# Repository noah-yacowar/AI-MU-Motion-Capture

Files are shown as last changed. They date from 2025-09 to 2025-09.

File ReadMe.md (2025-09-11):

# The "AI-MU" Motion-Capture Project

ESP8266 + BNO08x (080/085) based motion capture system that streams IMU data over Wi-Fi into Unity.  
The ecosystem includes a **mobile app** for QR code–based pairing of IMU suits and servers, making setup fast and reliable. This was chosen especially for commercial use cases where multiple users will be using the system daily. Here, a simple fixed connection from the sensor directly to the server is not flexible enough for all workflows.
The Unity application performs real-time skeleton reconstruction, visualization, and recording, with the ability to export captured motion to **BVH** for animation workflows.

---

## 📸 Overview

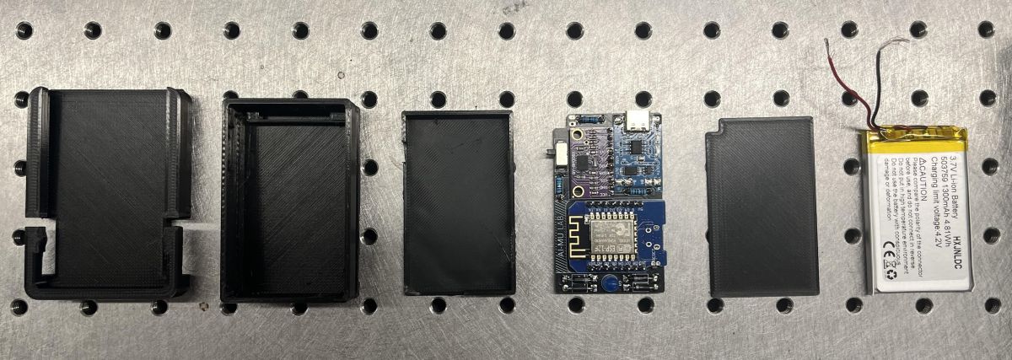
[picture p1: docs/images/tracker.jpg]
Tracker Hardware
  
*Custom ESP8266 D1 Mini + BNO08x tracker module*

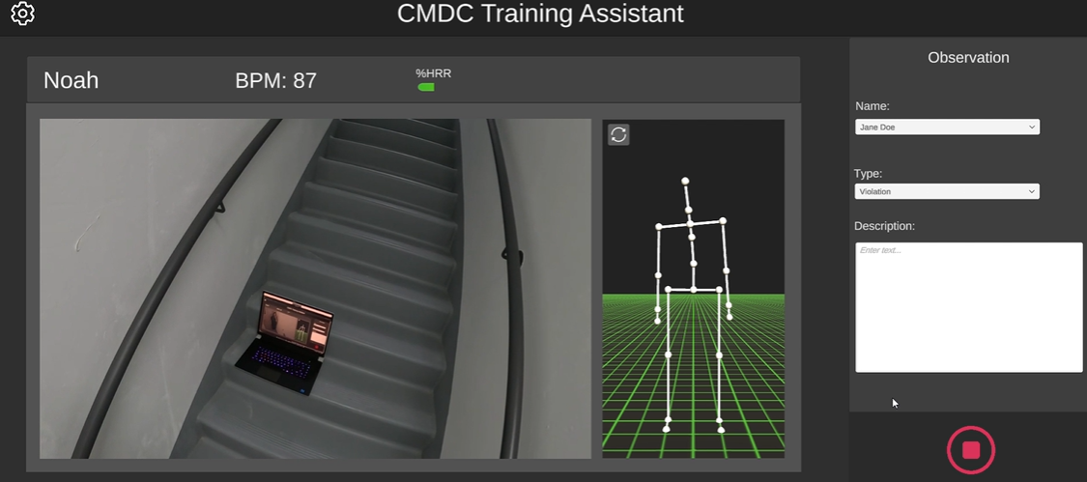
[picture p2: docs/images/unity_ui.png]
Unity UI
  
*Unity interface showing live skeleton and recording controls*

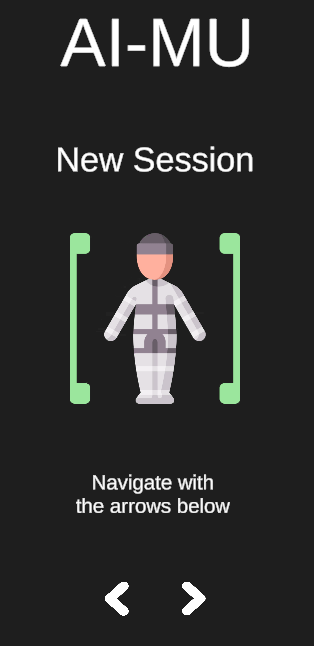
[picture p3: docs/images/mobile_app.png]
Mobile App
  
*Mobile app used to scan QR code of IMU suit and connect to server*

---

## ✨ Features

- **Low-cost IMU Trackers**: ESP8266 D1 Mini boards with BNO080/BNO085 IMUs.
- **Mobile App Integration**: Scan a QR code on the IMU suit to automatically configure and connect to the server.  
- **Wi-Fi Data Streaming**: Fast UDP packets (~100 Hz) from multiple trackers.
- **Real-time Visualization**: Unity app reconstructs skeletons live.
- **Calibration Tools**: Mounting error correction + baseline yaw alignment.
- **Multi-Participant Support**: Capture multiple people simultaneously.
- **Recording & Export**: Save sessions and export to **BVH** (for Blender, Unity, Maya, etc.).

---

## 🖥️ Software

- **Firmware**: C++/Arduino code running on each D1 Mini, sending IMU quaternions via UDP.  
- **Mobile App**:  
  - Scans QR code on the IMU suit to register tracker IDs.  
  - Connects suit to the Unity server automatically.  
- **Unity App**:  
  - Receives tracker data  
  - Maps IMUs to skeleton joints  
  - Provides calibration tools  
  - Records sessions and exports animations  

---

## 📦 Hardware

Each tracker is built from:

- **ESP8266 D1 Mini (Wemos)**  
- **BNO080 / BNO085 IMU sensor** (I²C connection)  
- **Battery + charging module**  
- 3D printed case (friction-fit lid for quick access)  

📷 Images:  

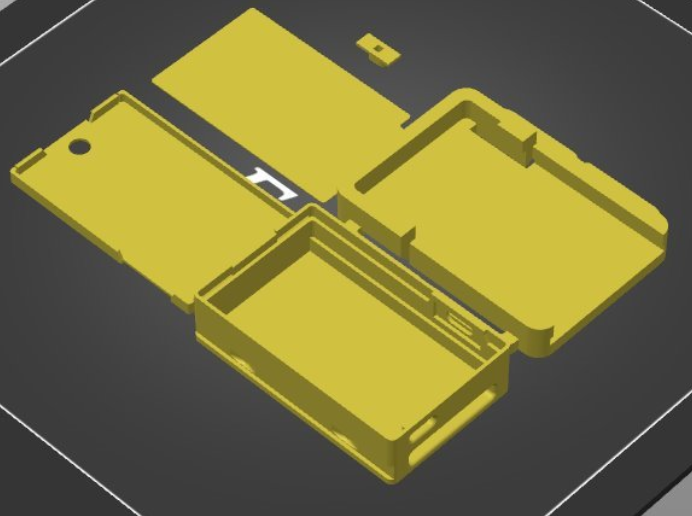
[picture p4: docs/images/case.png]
3D Printed Case
  
*Friction-fit printed case for tracker module*

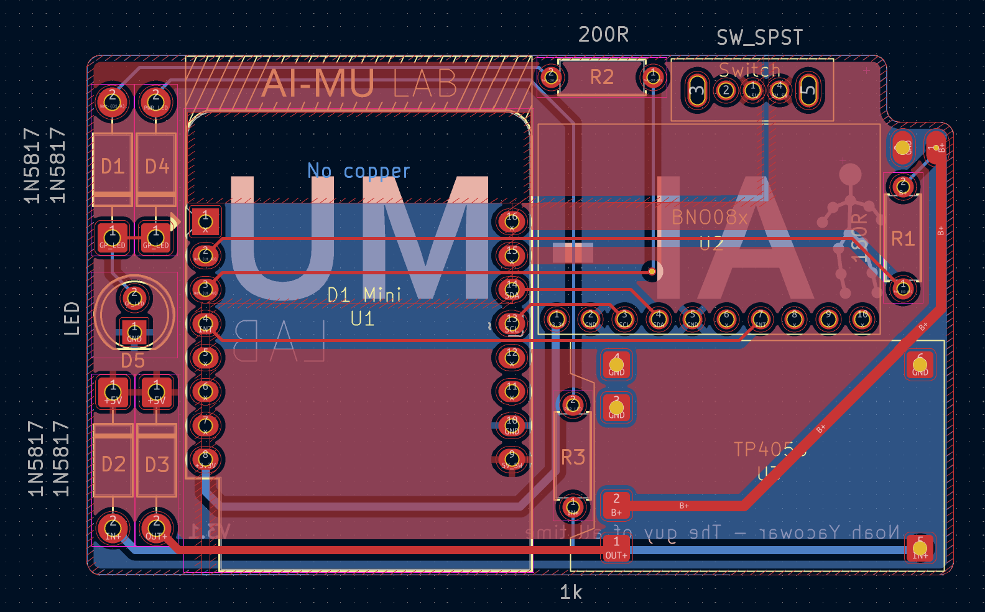
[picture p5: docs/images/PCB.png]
PCB Layout
  
*PCB layout in Kicad*

---

## 🚀 Getting Started

### 1. Clone the Repository
```bash
git clone https://github.com/noah-yacowar/AI-MU-Motion-Capture.git
cd AI-MU-Motion-Capture

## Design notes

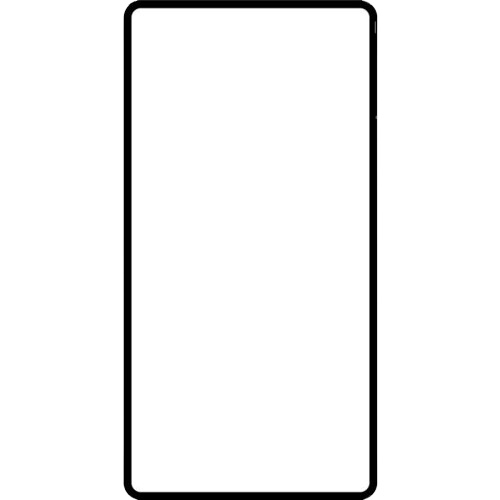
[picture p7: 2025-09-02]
Software/Mobile_App/Assets/MaskShapes/plsss-removebg-preview (2).png

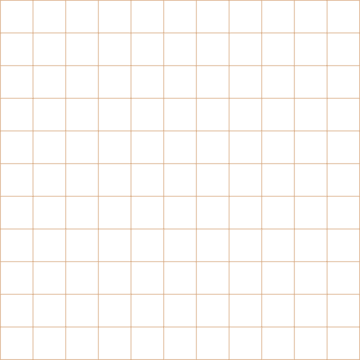
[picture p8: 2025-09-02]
Software/Server_App/Assets/Prefabs/Models/General/Skeleton/GridTexture.png

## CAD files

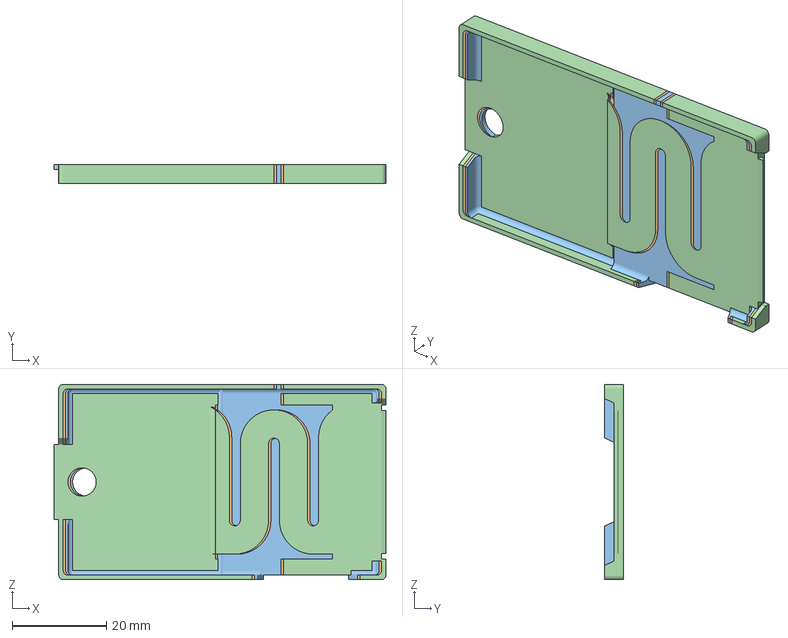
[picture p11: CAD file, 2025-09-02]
Hardware/Case/V2/Slicer/slicer_full_tracker.3mf
70.4 x 4.00 x 41.4 mm
Top_1.5mm.STL
Top_1mm.STL
Top_Friction.STL
Top_V2.4.STL

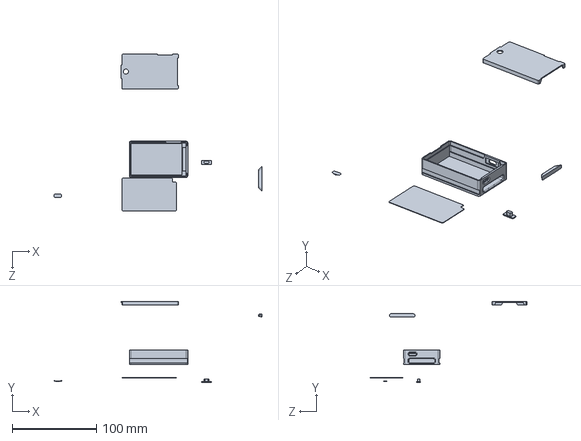
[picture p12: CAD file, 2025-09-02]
Hardware/Case/V2/RoughArea/Tracker_Main_Base.SLDPRT
247.4 x 96.4 x 186.3 mm

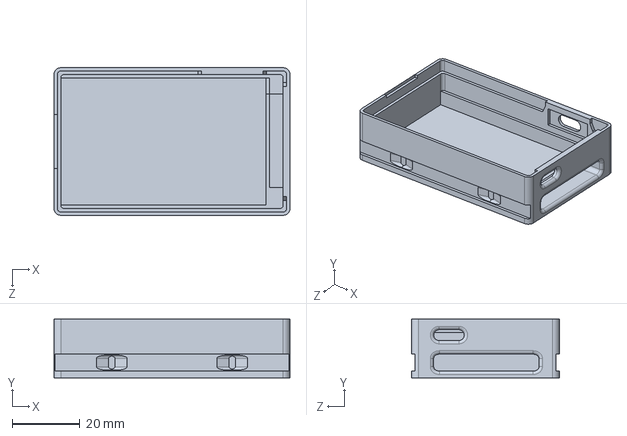
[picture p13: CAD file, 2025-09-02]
Hardware/Case/V2/Main_Body_V2.2.SLDPRT
69.5 x 17.3 x 43.5 mm

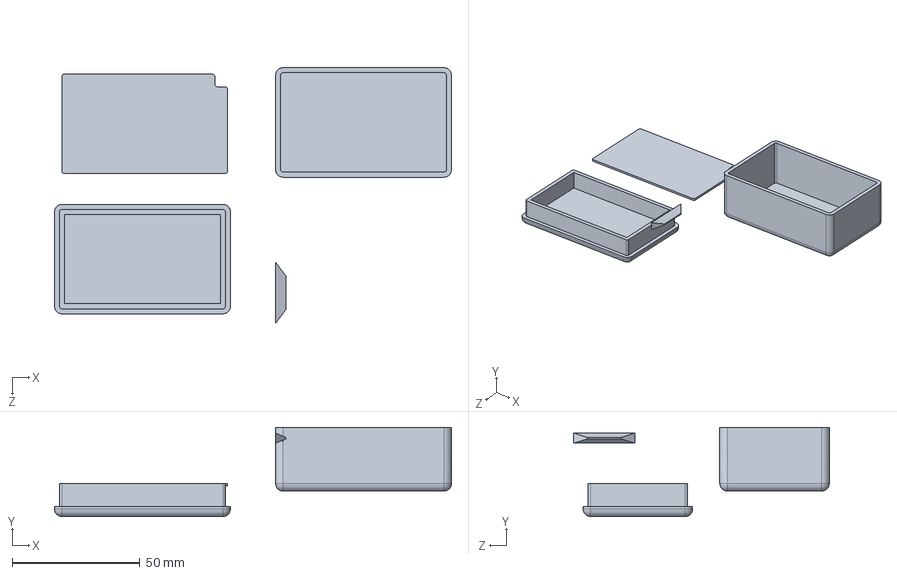
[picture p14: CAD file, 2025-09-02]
Hardware/Case/V2/RoughArea/MoreRough/Tracker_Housing_Top.SLDPRT
155.7 x 35.0 x 100.3 mm

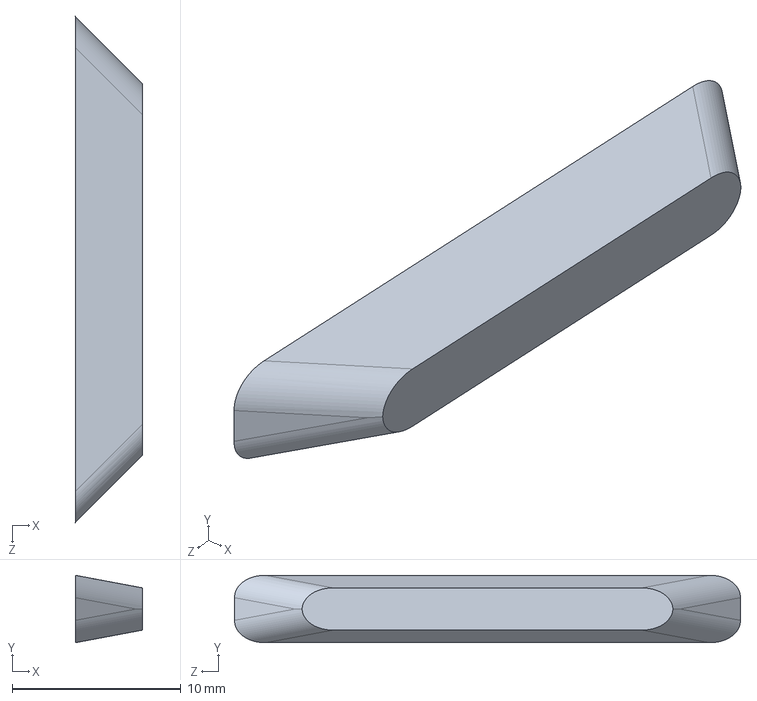
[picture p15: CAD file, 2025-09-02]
Hardware/Case/V2/RoughArea/Tracker_Housing_Connector_Insert.SLDPRT
4.00 x 4.00 x 30.0 mm

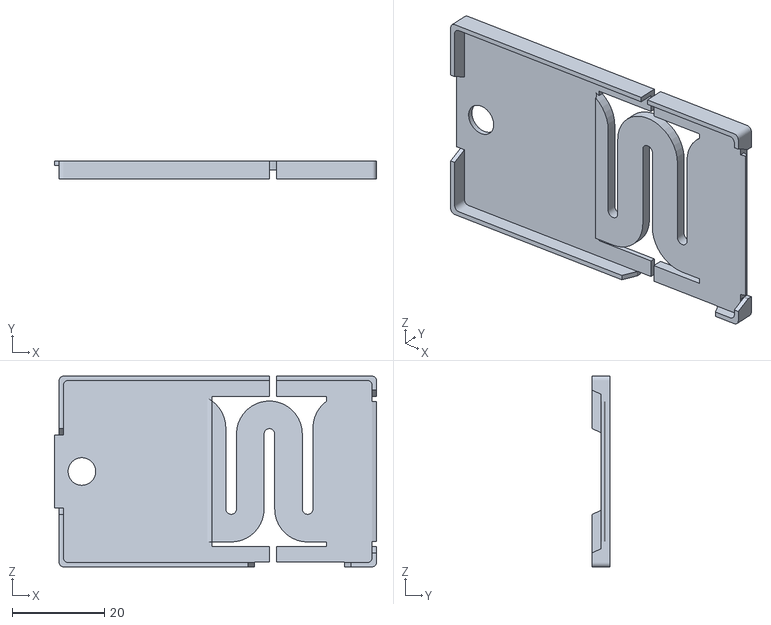
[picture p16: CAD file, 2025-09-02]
Hardware/Case/V2/STL/Top_1.5mm.STL
69.9 x 4.00 x 41.4

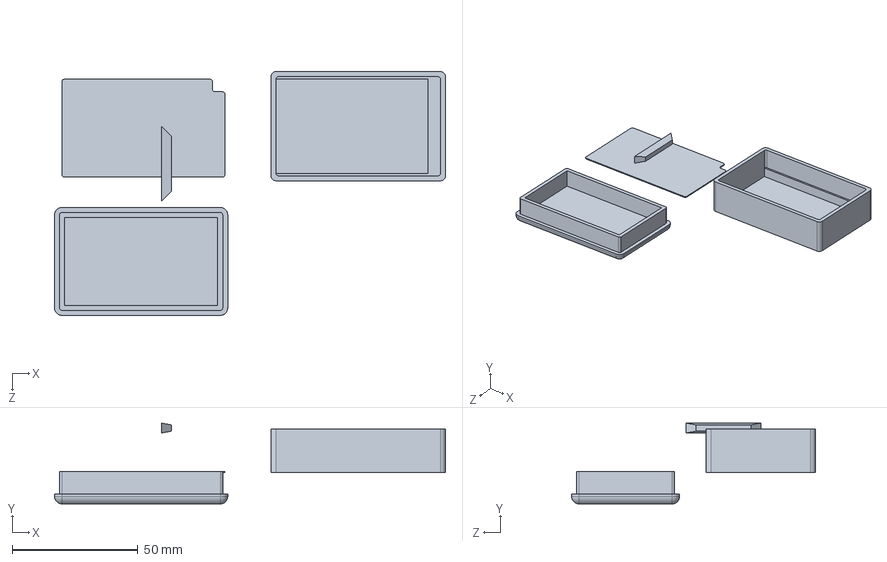
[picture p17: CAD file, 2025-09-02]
Hardware/Case/V2/RoughArea/MoreRough/Tracker_Housing.SLDPRT
155.7 x 32.2 x 97.1 mm

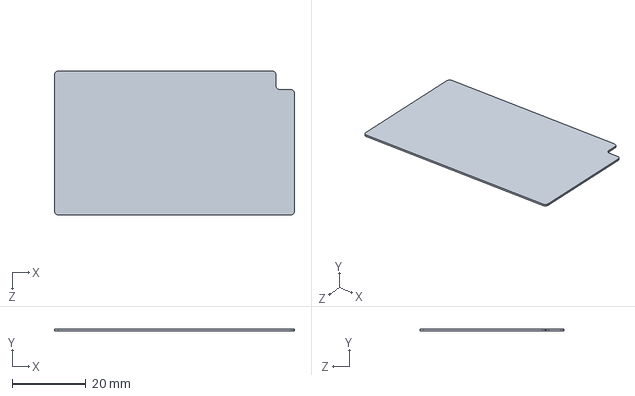
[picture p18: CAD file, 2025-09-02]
Hardware/Case/V2/Seperator_V2.2.SLDPRT
65.0 x 0.5 x 39.0 mm

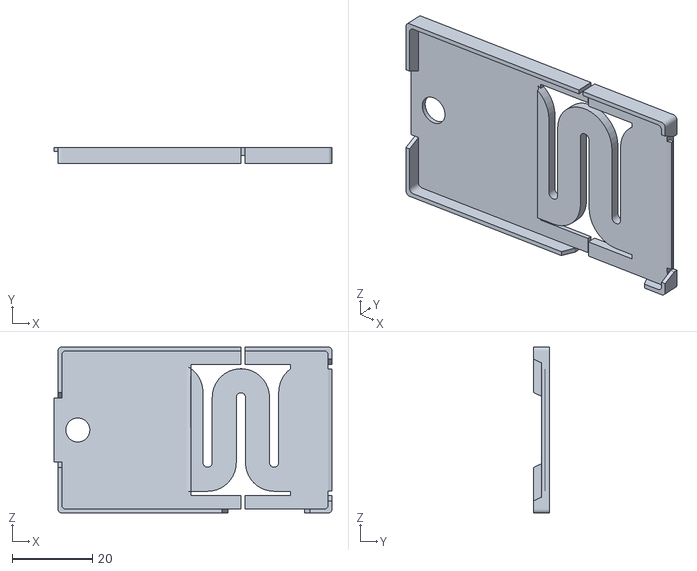
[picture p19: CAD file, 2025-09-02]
Hardware/Case/V2/STL/Top_1mm.STL
69.4 x 4.00 x 41.4

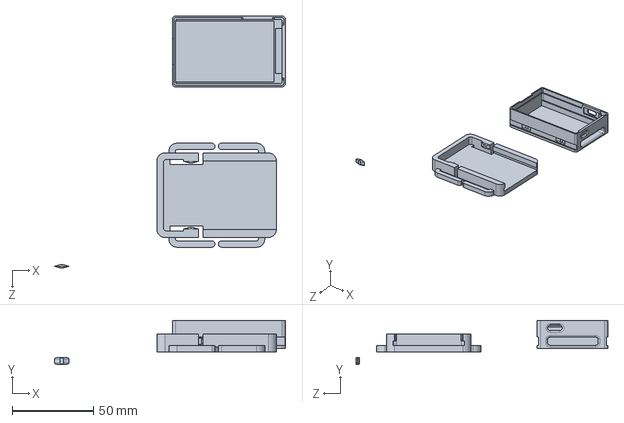
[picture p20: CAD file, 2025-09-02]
Hardware/Case/V2/RoughArea/Tracker_Housing_With_Cutouts.SLDPRT
141.9 x 27.2 x 154.7 mm

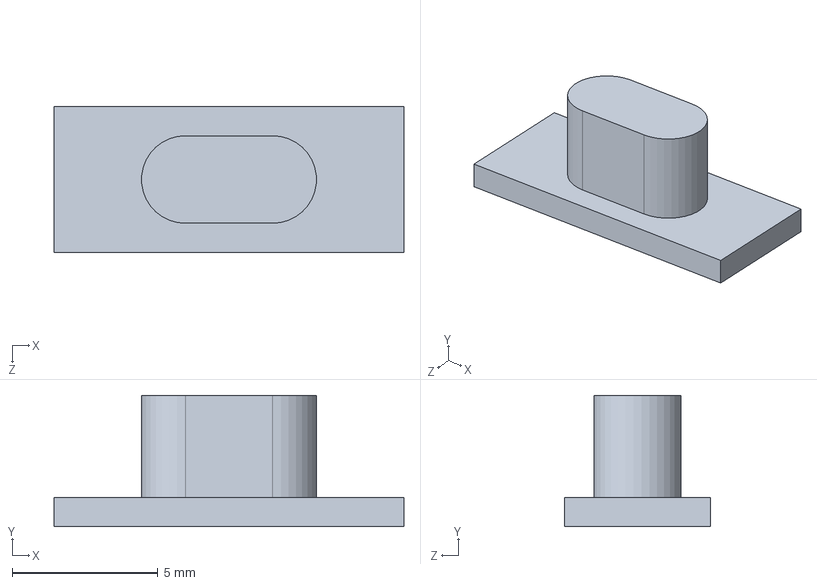
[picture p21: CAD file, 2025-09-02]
Hardware/Case/V2/Switch_V2.2.SLDPRT
12.0 x 4.50 x 5.00 mm

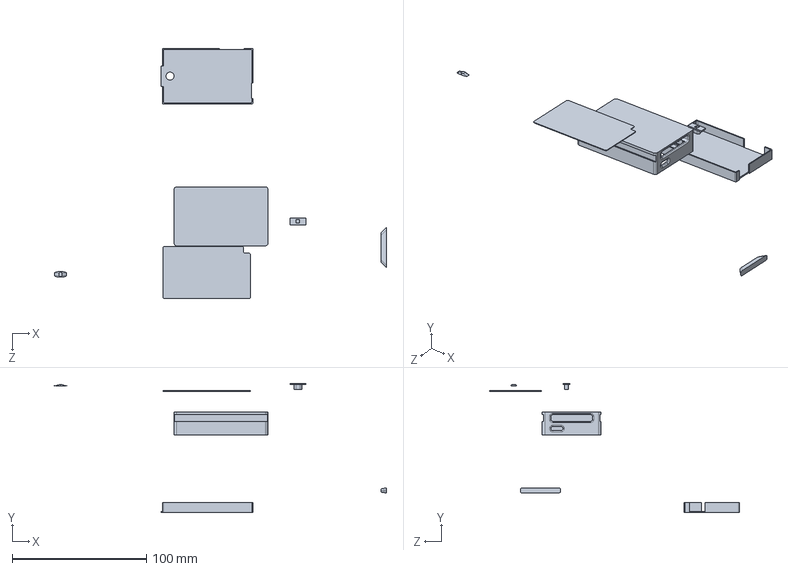
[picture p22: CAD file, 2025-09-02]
Hardware/Case/V2/RoughArea/Top_Housing_V2.1.SLDPRT
247.4 x 96.4 x 186.6 mm

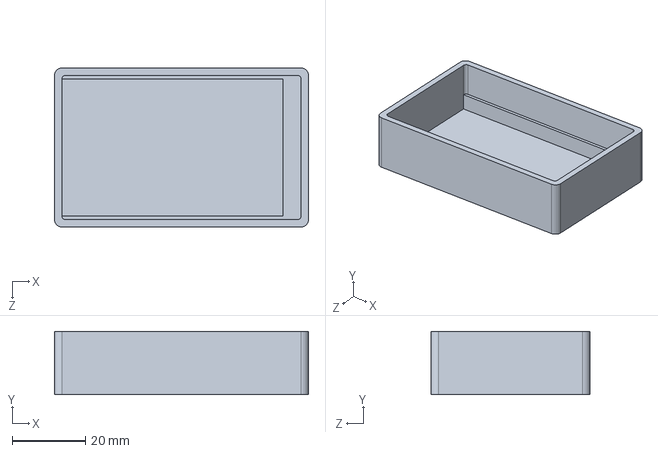
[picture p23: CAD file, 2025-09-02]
Hardware/Case/V2/RoughArea/Tracker_Housing_Body.SLDPRT
69.5 x 17.3 x 43.5 mm

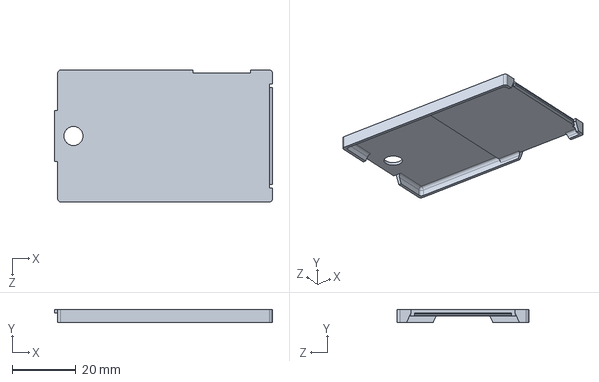
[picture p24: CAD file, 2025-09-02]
Hardware/Case/V2/Top_Friction.SLDPRT
68.4 x 4.00 x 41.4 mm

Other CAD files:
Hardware/Case/V2/RoughArea/Tracker_Housing_Connecting_Piece.SLDPRT
Hardware/Case/V2/Holder_V2.2.SLDPRT
Hardware/Case/V2/RoughArea/Tracker_Housing_Seperator.SLDPRT
Hardware/Case/V2/Top_Unstretched.SLDPRT
Hardware/Case/V1/Body.SLDPRT
Hardware/Case/V1/Divider.SLDPRT
Hardware/Case/V1/Lid.SLDPRT
Hardware/Case/V1/Mount.SLDPRT
Hardware/Case/V1/Print_Files/Body.3mf
Hardware/Case/V1/STL/Body.STL
Hardware/Case/V1/STL/Divider.STL
Hardware/Case/V1/STL/Lid.STL
Hardware/Case/V1/STL/Mount.STL
Hardware/Case/V2/STL/Holder_V2.2.STL
Hardware/Case/V2/STL/Seperator_V2.2.STL
Hardware/Case/V2/STL/Switch_V2.2.STL
Hardware/Case/V2/STL/Top_Friction.STL
Hardware/Case/V2/STL/Top_V2.3.STL
Hardware/Case/V2/STL/Top_V2.4.STL
Hardware/Case/V2/Top_V2.2.SLDPRT
Hardware/Case/V2/Top_V2.3.SLDPRT
Hardware/Case/V2/Top_V2.4.SLDPRT

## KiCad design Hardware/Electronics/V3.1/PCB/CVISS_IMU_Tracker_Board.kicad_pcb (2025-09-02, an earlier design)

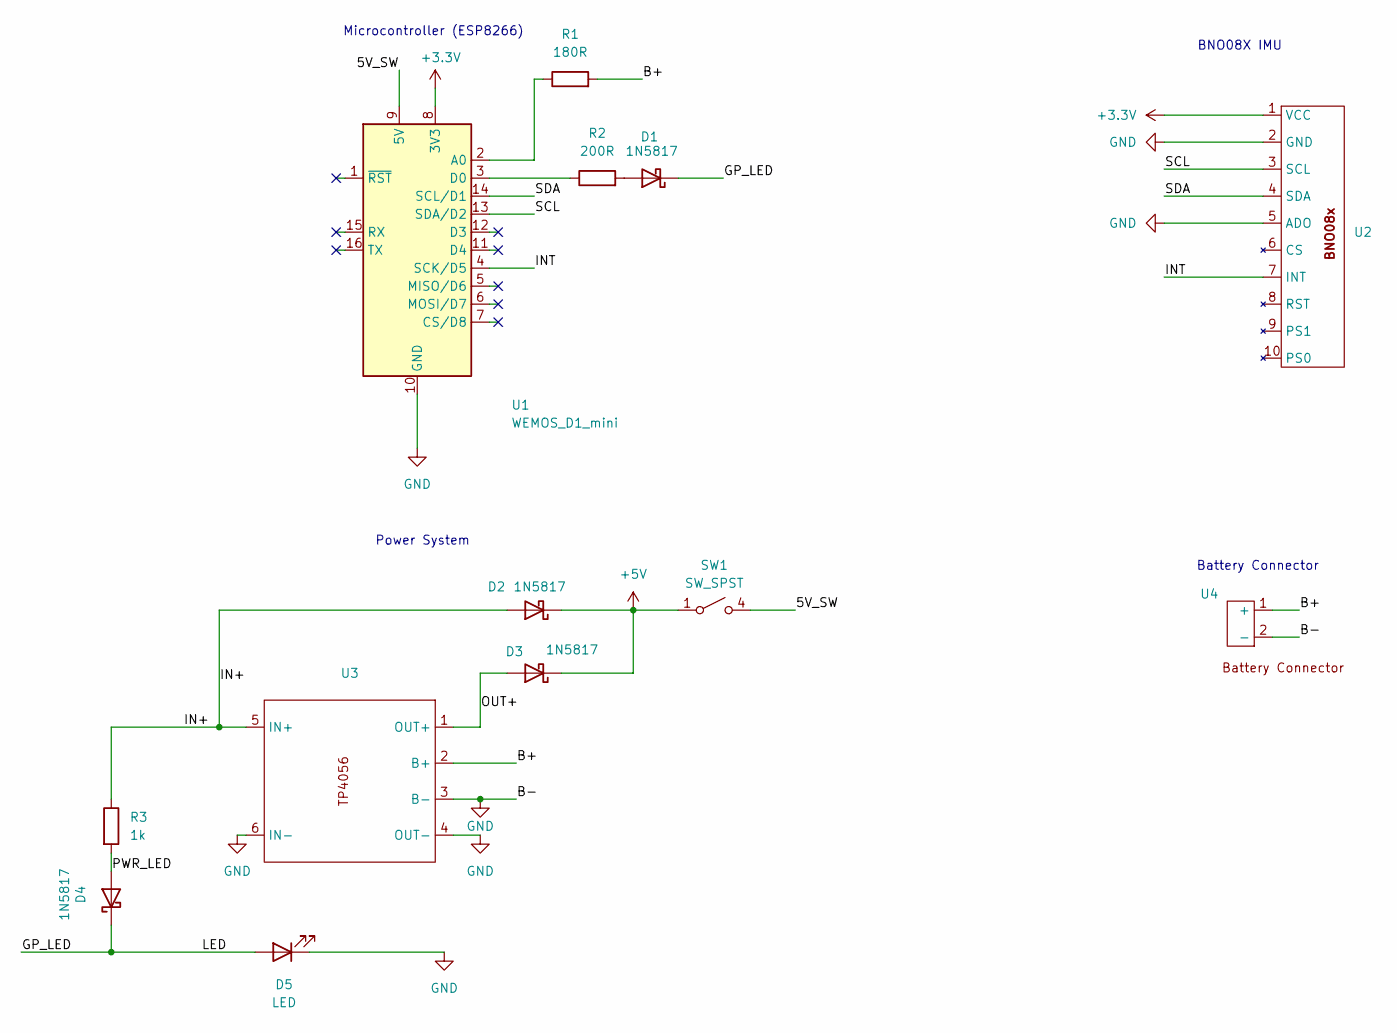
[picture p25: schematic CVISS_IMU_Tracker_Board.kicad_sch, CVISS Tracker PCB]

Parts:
D1, D2, D3, D4: 1N5817; D_DO-41_SOD81_P10.16mm_Horizontal
D5: LED; LED_D5.0mm_Clear
R1: 180R; R_Axial_DIN0207_L6.3mm_D2.5mm_P7.62mm_Horizontal
R2: 200R; R_Axial_DIN0207_L6.3mm_D2.5mm_P7.62mm_Horizontal
R3: 1k; R_Axial_DIN0207_L6.3mm_D2.5mm_P7.62mm_Horizontal
SW1: SW_SPST; SK12DO7_Switch
U1: WEMOS_D1_mini; WEMOS_D1_mini_light
U2: BNO08x_Board
U3: TP4056_Board
U4: Battery_Connector

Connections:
+3.3V: U1.8 (3V3), U2.1 (VCC)
+5V: D2.1 (K), D3.1 (K), SW1.1 (A)
/5V_SW: SW1.4 (B), U1.9 (5V)
/B+: R1.2, U3.2 (B+), U4.1 (+)
/GP_LED: D1.1 (K), D4.1 (K), D5.2 (A)
/IN+: D2.2 (A), R3.1, U3.5 (IN+)
/INT: U1.4 (SCK/D5), U2.7 (INT)
/OUT+: D3.2 (A), U3.1 (OUT+)
/PWR_LED: D4.2 (A), R3.2
/SCL: U1.13 (SDA/D2), U2.3 (SCL)
/SDA: U1.14 (SCL/D1), U2.4 (SDA)
GND: D5.1 (K), U1.10 (GND), U2.2 (GND), U2.5 (ADO), U3.3 (B-), U3.4 (OUT-), U3.6 (IN-), U4.2 (-)
unnamed: D1.2 (A), R2.2
unnamed: R1.1, U1.2 (A0)
unnamed: R2.1, U1.3 (D0)

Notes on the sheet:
BNO08X IMU
Power System
Microcontroller (ESP8266)
Battery Connector

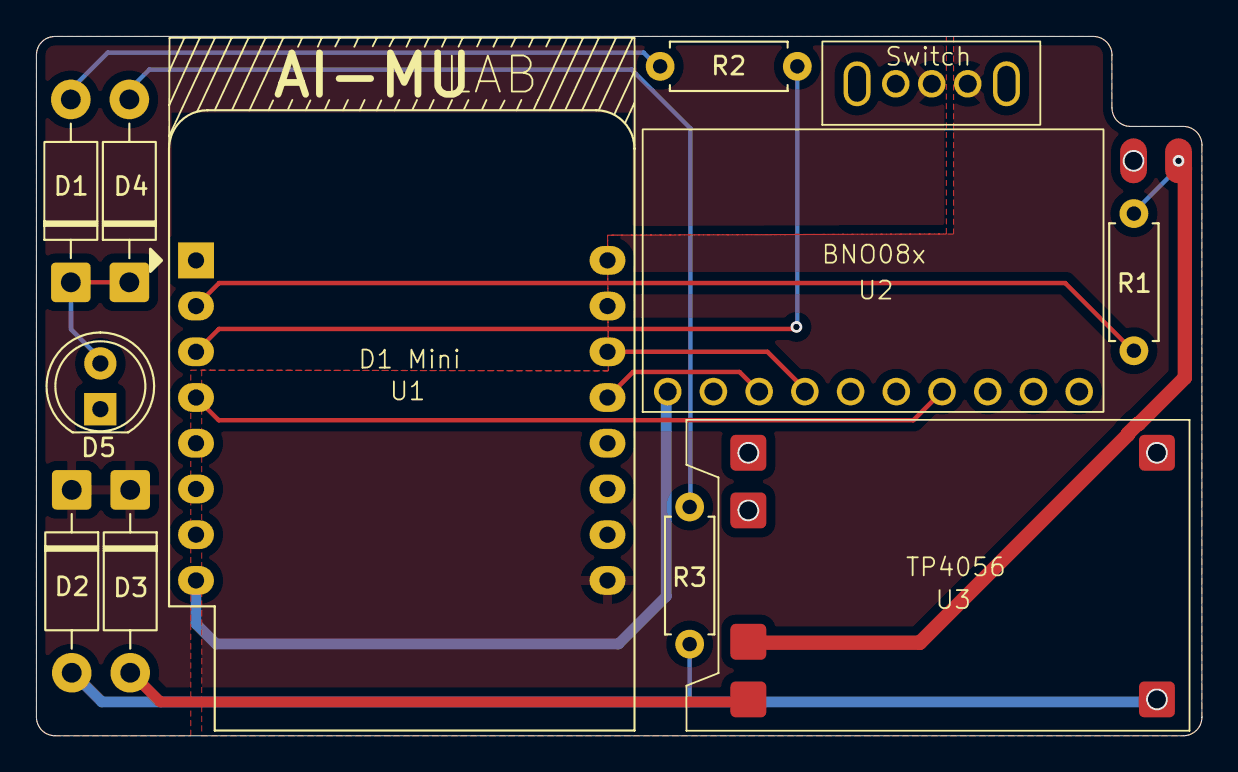
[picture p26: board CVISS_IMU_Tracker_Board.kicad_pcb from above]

Board: 2 copper layers, 64.7 x 38.9 mm, 13 parts (0 on the bottom side), 15 nets.

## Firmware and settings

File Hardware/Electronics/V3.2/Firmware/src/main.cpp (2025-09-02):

#include <ESP8266WiFi.h>
#include <WiFiUdp.h>
#include "BNO08x/BNO08x.h"
#include "DataTypes/Quaternion.h"
#include "Networking/ConnectionManager.h"
#include "configuration/TrackerConfiguration.h"
#include "configuration/NetworkConfiguration.h"

unsigned long lastSendTime = 0;

WiFiUDP udp;
BNO08x imu(D1, D2, 0x4A, D5);

void setup() {
    Serial.begin(115200);
    delay(1000);
    ConnectionManager::begin(SSID, PASS, SERVER_IP, SERVER_PORT); 

    if (!imu.begin()) 
    {
        Serial.println("IMU not detected.");
        while (true) delay(1000);
    }

    Serial.println("IMU Initialized.");
}

void loop() 
{
    unsigned long now = millis();

    if (now - lastSendTime >= IMU_PERIOD_MS) 
    {
        lastSendTime = now;

        if (imu.update()) 
        {
            Quaternion corrected = imu.GetCorrectedQuaternion();

            // Format: SUIT_ID:JOINT:quat_values
            String packet = JOINT;
            packet += ":";
            packet += imu.getQuatString(corrected);

            ConnectionManager::sendMessage(packet);
        }
    }
}

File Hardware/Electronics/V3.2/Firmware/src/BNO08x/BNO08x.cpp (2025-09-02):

#include "BNO08x.h"
#include <DataTypes/Quaternion.h>
#include "configuration/TrackerConfiguration.h"

BNO08x::BNO08x(uint8_t sda, uint8_t scl, uint8_t imuAddr, uint8_t intPin)
  : address(imuAddr), sdaPin(sda), sclPin(scl), intPinNumber(intPin),
    gpioInt(intPin), intPinInterface(&gpioInt) {}

bool BNO08x::begin() 
{
  delay(100);
  Wire.begin(sdaPin, sclPin);
  Wire.setClock(100000); 
  delay(100);

  imu.enableDebugging(Serial);
  if (!imu.begin(address, Wire, intPinInterface)) 
  {
    Serial.println("Failed to initialize BNO080.");
    return false;
  }

  Serial.println("BNO080 connected.");
  imu.enableGameRotationVector(IMU_PERIOD_MS);  // 100Hz

  // Apply a fixed 90° pitch offset
  offsetQuat = Quaternion::EulerToQuat(90.0f, 0.0f, 0.0f);

  return true;
}

bool BNO08x::update() 
{
  if (imu.dataAvailable()) {
    //imu.getGameQuat(qx, qy, qz, qw, accuracy);
    float radAccuracy;
    imu.getQuat(qx, qy, qz, qw, radAccuracy, accuracy);
    //Serial.printf("Quat: %.4f, %.4f, %.4f, %.4f | Accuracy: %d\n",
    //              qx, qy, qz, qw, accuracy);
    return true;
  }
  return false;
}

String BNO08x::getQuatString(const Quaternion& q)
{
    return String(q.x, 4) + "," + String(q.y, 4) + "," + String(q.z, 4) + "," + String(q.w, 4);
}

Quaternion BNO08x::GetCurrentQuaternion() 
{
    return Quaternion(qx, qy, qz, qw);
}

bool BNO08x::Calibrate() 
{
  /* This function is no longer needed */

    Serial.println("Waiting for IMU reading to calibrate...");

    // Wait until we get a valid reading
    while (!update()) 
    {
        delay(10); // small delay to avoid busy loop
    }

    Quaternion identityQuat = GetCurrentQuaternion();
    offsetQuat = identityQuat.inverse();  // store inverse as offset

    Serial.println("Calibration complete.");

    return true;
}

Quaternion BNO08x::GetCorrectedQuaternion() 
{
  return offsetQuat * GetCurrentQuaternion();
}

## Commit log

2025-09-02 Remove HR and camera feed
2025-09-08 Removed bloat
    [pyvenv.cfg]
2025-09-11 Electronics folder
    [CVISS_IMU_Tracker_Board-B_Cu.gbr, CVISS_IMU_Tracker_Board-B_Mask.gbr, CVISS_IMU_Tracker_Board-B_Paste.gbr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]
2025-09-11 Add PCB to readme
